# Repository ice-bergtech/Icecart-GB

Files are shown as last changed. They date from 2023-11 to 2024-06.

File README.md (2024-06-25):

# Icecart-GB

Another ROM Cartridge for the Gameboy.
Purpose is to fit the form factor of a gameboy cartridge and act as a ROM cartridge while also providing an arduino-like interface.
Emulates the functionality of an official cart, with the different bank controllers implemented in software.

[Schematic](GB-ICECART-GB-Alpha/schematic/GB-ICECART-GB.pdf)

PCB

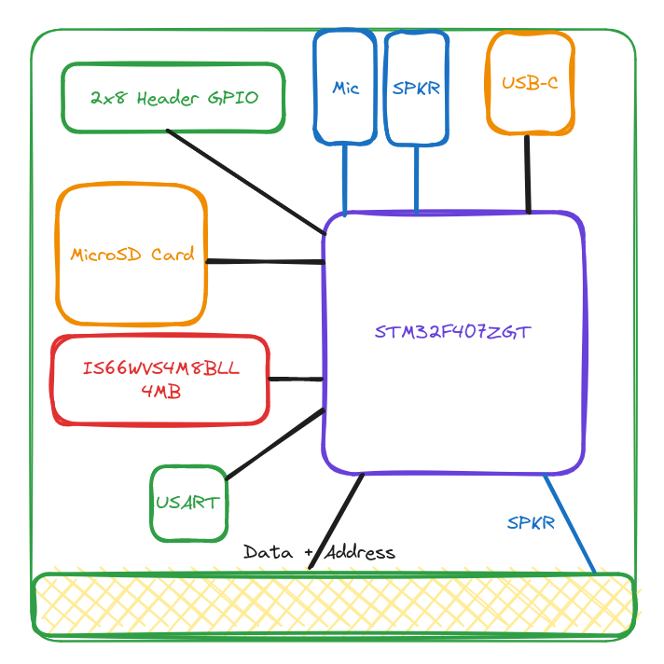
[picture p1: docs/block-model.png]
Block Model


It should also have functionality similar to an arduino, where you can interface with it through GPIO and audio in/out.
It should be as low-power as possible, since it will run off the gameboy battery.
It should support an sd card for storage while powered off.

Requirements:

* STM32-type processor
  * low power
  * Enough pins for cart and GPIO (32+16)
  * rtc
* External mic + speaker 3.8mm jacks
* dac connection to gameboy cartridge audio line for input
* usb C for programming / updating
* 2x8 or 2x6 GPIO
* microsd card slot for storage
* 32Mbit serial ram
* Respond to gameboy cartridge read/write (1MHz ??? Not sure) 
  * 4Mihz for gameboy: [gekkio notes](https://gekkio.fi/files/gb-docs/gbctr.pdf) appendix C
  * 8Mihz for gameboy color?
  * More timing information: https://dhole.github.io/post/gameboy_cartridge_emu_1/
* gameboy dmg/color cartridge footprint
  * https://github.com/Gekkio/gb-hardware/tree/main/GB-BRK-CART
* FreeRTOS

Examples:

* emeryth-hacks: https://emeryth.net/stm32-game-boy-cartridge/
* gekkio: https://github.com/Gekkio/gb-hardware#gb-live32

References:

[Old Memory bank controllers](https://mgba-emu.github.io/gbdoc/#mbc)
[TPP1 mapper](https://github.com/aaaaaa123456789/tpp1)

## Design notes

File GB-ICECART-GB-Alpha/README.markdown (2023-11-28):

# Notes

* The power LED (+ resistor) and the bypass capacitor are optional.
* The value of R1 might be too high to get enough current for the LED and can
  be replaced with a lower value if necessary. The value is set quite high to
  minimize power usage and still works fine with the components I use.
* All parts in the BOM can be replaced with pretty much any similar parts.

## Memory

8 Megabit SRAM

https://www.mouser.com/ProductDetail/ISSI/IS66WVS4M8BLL-104NLI?qs=doiCPypUmgHfByEUFkOsAw%3D%3D
https://www.issi.com/WW/pdf/66-67WVS4M8ALL-BLL.pdf

SPI

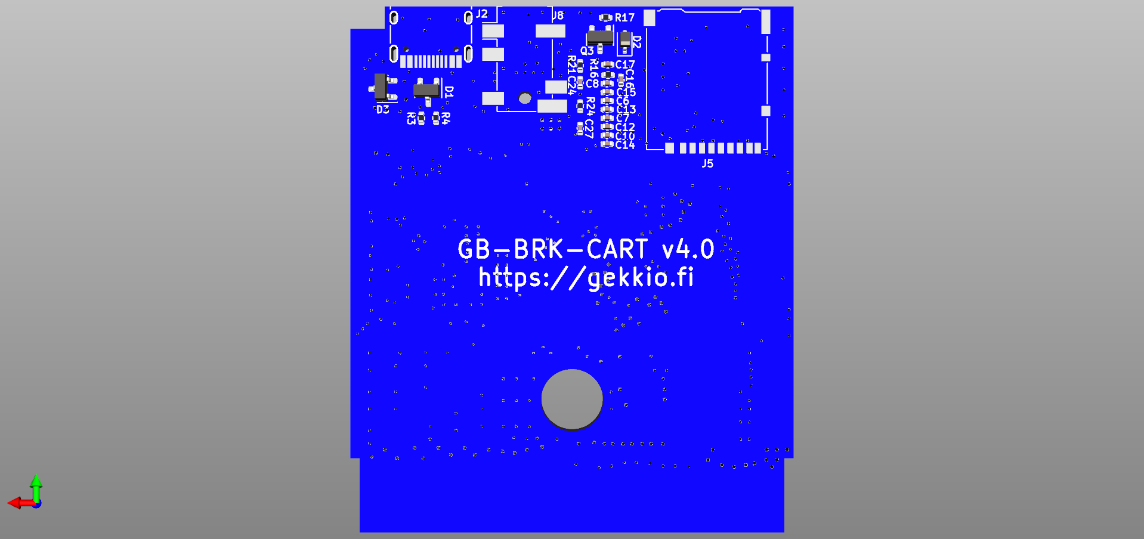
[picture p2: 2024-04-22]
ICECART-GB/images/GAMEBOY_STM32_CART 1.png

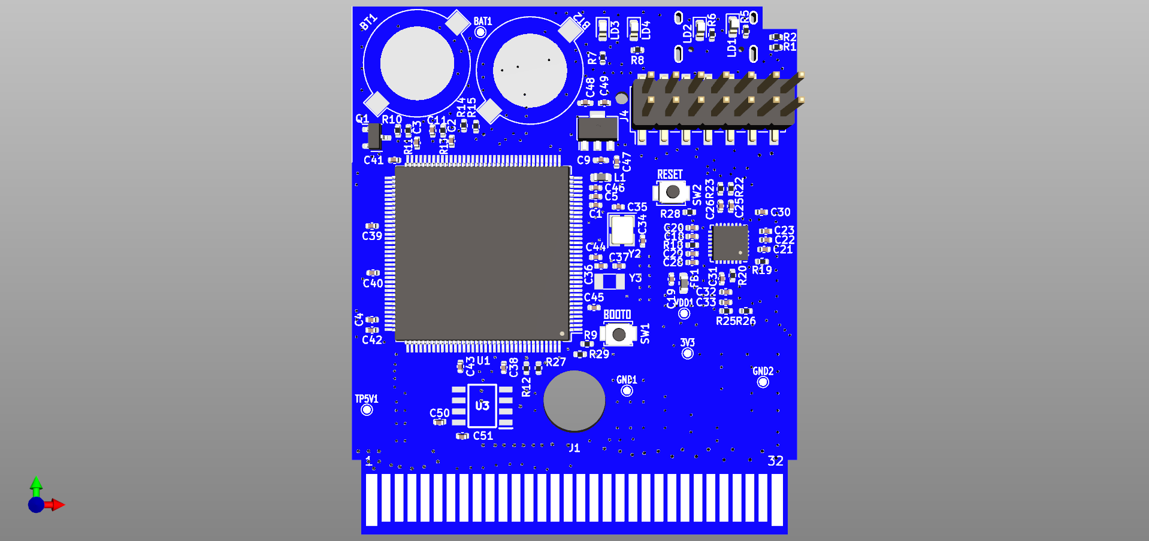
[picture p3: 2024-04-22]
ICECART-GB/images/GAMEBOY_STM32_CART.png

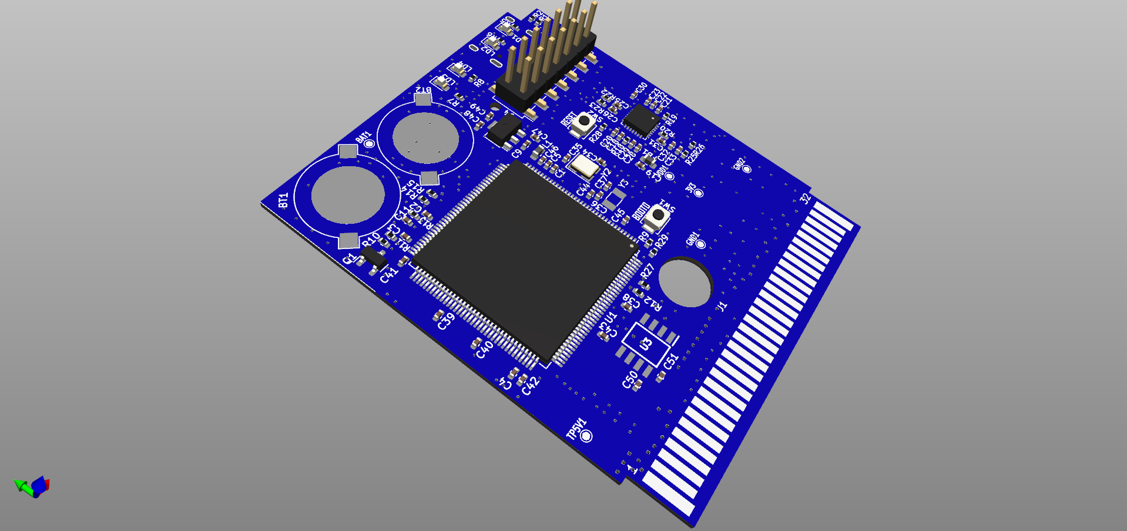
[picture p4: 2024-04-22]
ICECART-GB/images/GAMEBOY_STM32_CART 2.png

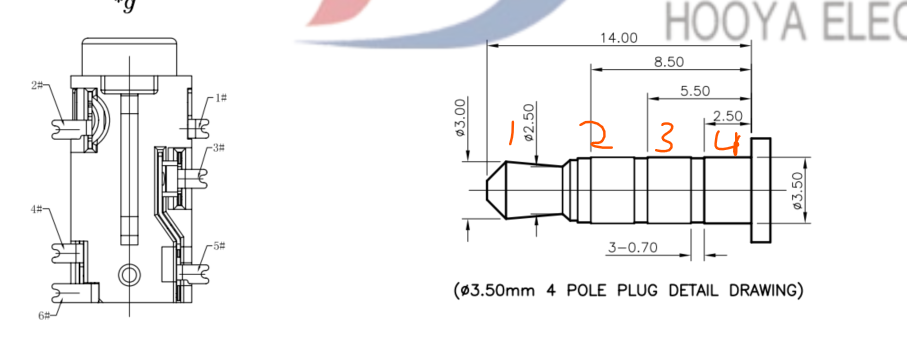
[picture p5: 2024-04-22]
ICECART-GB/ASSETS/mic_connection.png

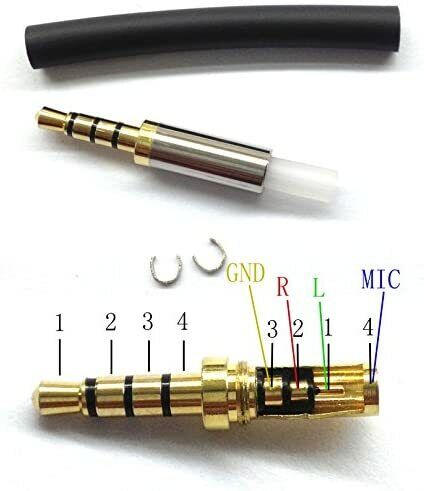
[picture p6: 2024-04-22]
ICECART-GB/ASSETS/jack_connection.png

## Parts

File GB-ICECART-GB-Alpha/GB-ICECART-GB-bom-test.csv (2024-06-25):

Reference | Value | Datasheet | Footprint | Qty | DNP
C1,C2 | 15p | -- mixed values -- | Capacitor_SMD:C_0603_1608Metric | 2
C3,C4 | 2.2uF |  | Capacitor_SMD:C_0603_1608Metric | 2
C5 | 10 | ~ | Capacitor_SMD:C_0603_1608Metric | 1
C6,C7,C8,C9,C10,C12,C13,C14,C15 | 100nF | -- mixed values -- | Capacitor_SMD:C_0603_1608Metric | 9
C11 | 0.1uF |  | Capacitor_SMD:C_0603_1608Metric | 1
C16 | 1uF | ~ | Capacitor_SMD:C_0603_1608Metric | 1
J1,MK1,MK2 | DNF |  | -- mixed values -- | 3
J2 | TYPE-C-31-M-12 | https://www.usb.org/sites/default/files/documents/usb_type-c.zip | Connector_USB:USB_C_Receptacle_HRO_TYPE-C-31-M-12 | 1
J3 | AudioJack3 | ~ | Connector_Audio:Jack_3.5mm_CUI_SJ1-3523N_Horizontal | 1
J4 | Conn_02x08_Odd_Even | ~ | Connector_IDC:IDC-Header_2x08_P2.54mm_Vertical_SMD | 1
J5 | Micro_SD_Card_Det | https://www.hirose.com/product/en/download_file/key_name/DM3/category/Catalog/doc_file_id/49662/?item_id=195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 | Connector_Card:microSD_HC_Hirose_DM3AT-SF-PEJM5 | 1
L1 | L | ~ | Inductor_SMD:L_6.3x6.3_H3 | 1
LD1 | Green | ~ | LED_SMD:LED_0603_1608Metric | 1
LD2 | Orange | ~ | LED_SMD:LED_0603_1608Metric | 1
LD3 | RED | ~ | LED_SMD:LED_0603_1608Metric | 1
LD4 | Blue | ~ | LED_SMD:LED_0603_1608Metric | 1
Q1 | AO3401A | http://www.aosmd.com/pdfs/datasheet/AO3401A.pdf | Package_TO_SOT_SMD:SOT-23 | 1
R1,R2 | 5k1 | ~ | Resistor_SMD:R_0603_1608Metric | 2
R3,R4 | 20 | ~ | Resistor_SMD:R_0603_1608Metric | 2
R5,R6,R7,R8 | 510 | ~ | Resistor_SMD:R_0603_1608Metric | 4
R9 | 10k | ~ | Resistor_SMD:R_0603_1608Metric | 1
R10,R11,R13,R14,R15 | 47K | ~ | Resistor_SMD:R_0603_1608Metric | 5
R16 | 0 | ~ | Resistor_SMD:R_0603_1608Metric | 1
SW1 | SW_Push | ~ | Button_Switch_SMD:SW_SPST_B3U-1000P | 1
U1 | STM32F407ZGTx | http://www.st.com/st-web-ui/static/active/en/resource/technical/document/datasheet/DM00037051.pdf | Package_QFP:LQFP-144_20x20mm_P0.5mm | 1
U2 | HT75xx-1-SOT89 | https://www.holtek.com/documents/10179/116711/HT75xx-1v250.pdf | Package_TO_SOT_SMD:SOT-89-3 | 1
U3 | IS66WVS4M8BLL-104NLI |  | IS66WVS4M8BLL:SOIC127P600X175-8N | 1
Y1 | Crystal 8M | ~ | Crystal:Crystal_SMD_TXC_7M-4Pin_3.2x2.5mm | 1

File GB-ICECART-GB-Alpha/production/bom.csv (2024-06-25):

Designator | Footprint | Quantity | Value | LCSC Part #
C1, C2 | 0603 | 2 | 15p | 06035C104KAT4A
C10, C12, C13, C14, C15, C6, C7, C8 | 0603 | 8 | 100nF
C11 | 0603 | 1 | 0.1uF | 06035C104KAT4A
C16 | 0603 | 1 | 1uF
C3, C4 | 0603 | 2 | 2.2uF | 06035C104KAT4A
C5 | 0603 | 1 | 10
C9 | 0603 | 1 | 100nF | 06035C104KAT4A
J1 | GameBoy_Cartridge_1x32_P1.50mm_Edge | 1 | DNF
J2 | USB_C_Receptacle_HRO_TYPE-C-31-M-12 | 1 | TYPE-C-31-M-12
J3 | Jack_3.5mm_CUI_SJ1-3523N_Horizontal | 1 | AudioJack3
J4 | IDC-Header_2x08_P2.54mm_Vertical_SMD | 1 | Conn_02x08_Odd_Even
J5 | microSD_HC_Hirose_DM3AT-SF-PEJM5 | 1 | Micro_SD_Card_Det
L1 | L_6.3x6.3_H3 | 1 | L
LD1 | 0603 | 1 | Green
LD2 | 0603 | 1 | Orange
LD3 | 0603 | 1 | RED
LD4 | 0603 | 1 | Blue
MK1 | MountingHole_7.2mm | 1 | DNF
Q1 | SOT-23 | 1 | AO3401A
R1, R2 | 0603 | 2 | 5k1
R10, R11, R13, R14, R15 | 0603 | 5 | 47K
R16 | 0603 | 1 | 0
R3, R4 | 0603 | 2 | 20
R5, R6, R7, R8 | 0603 | 4 | 510
R9 | 0603 | 1 | 10k
SW1 | SW_SPST_B3U-1000P | 1 | SW_Push
U1 | LQFP-144_20x20mm_P0.5mm | 1 | STM32F407ZGTx
U2 | SOT-89-3 | 1 | HT75xx-1-SOT89
U3 | SOIC127P600X175-8N | 1 | IS66WVS4M8BLL-104NLI
Y1 | Crystal_SMD_TXC_7M-4Pin_3.2x2.5mm | 1 | Crystal 8M

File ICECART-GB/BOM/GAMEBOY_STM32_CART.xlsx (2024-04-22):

Reference(s) | Value | Footprint | MPN | Vendor | Qty
BT1, BT2 | Battery_Cell | greencharge-footprints:AG10-LR1130-BUTTONCELL_BAT | https://www.alibaba.com/product-detail/Metal-alkaline-1-5V-AG10-LR1130_60831977476.html | Alibaba | 2
C1, C19, C23, C33, C51 | 10u | Capacitor_SMD:C_0402_1005Metric | CL05A106MQ5NUNC | LCSC | 5
C2, C6, C7, C8, C10, C11, C12, C13, C14, C15, C18, C20, C21, C22, C28, C29, C30, C32, C38, C39, C40, C41, C42, C43, C44, C45, C46, C50 | 100n | Capacitor_SMD:C_0402_1005Metric | CL05B104KB54PNC | LCSC | 28
C3, C4 | 2.2uF | Capacitor_SMD:C_0402_1005Metric | 06035C104KAT4A | LCSC | 2
C5, C47, C49 | 10u | Capacitor_SMD:C_0402_1005Metric | CL05A106MQ5NUNC | LCSC | 3
C9, C48 | 100nF | Capacitor_SMD:C_0402_1005Metric_Pad0.74x0.62mm_HandSolder | CL05B104KB54PNC | LCSC | 2
C16, C31 | 1uF | Capacitor_SMD:C_0402_1005Metric | CL05A105KO5NNNC | LCSC | 2
C17 | 4.7u | Capacitor_SMD:C_0402_1005Metric | CL05A475MQ5NRNC | LCSC | 1
C24, C25, C26, C27 | 22u | Capacitor_SMD:C_0402_1005Metric | GRM155R60J226ME11D | LCSC | 4
C34, C35, C36, C37 | 22p | Capacitor_SMD:C_0402_1005Metric | 06035C104KAT4A | LCSC | 4
D1, D3 | SP0502BAHT | Package_TO_SOT_SMD:SOT-23 | SP0502BAHTG | LCSC | 2
D2 | D_Schottky_Small | Diode_SMD:D_SOD-323 | B5817WS | LCSC | 1
FB1, L1 | L | Inductor_SMD:L_0603_1608Metric | BLM18SG121TN1D | LCSC | 2
J2 | TYPE-C-31-M-12 | Connector_USB:USB_C_Receptacle_HRO_TYPE-C-31-M-12 | TYPE-C-31-M-12 | LCSC | 1
J4 | Conn_02x08_Odd_Even | Connector_PinHeader_2.54mm:PinHeader_2x07_P2.54mm_Vertical_SMD | PZ254-2-07-S | LCSC | 1
J5 | Micro_SD_Card_Det | Connector_Card:microSD_HC_Hirose_DM3AT-SF-PEJM5 | DM3AT-SF-PEJM5 | LCSC | 1
J8 | AudioJack3_Ground | Connector_Audio:Jack_3.5mm_PJ31060-I_Horizontal | PJ-31060 | LCSC | 1
LD1 | Green | LED_SMD:LED_0603_1608Metric | LTST-C193KGKT-5A | LCSC | 1
LD2 | Orange | LED_SMD:LED_0603_1608Metric | LTST-C193KFKT-5A | LCSC | 1
LD3 | RED | LED_SMD:LED_0603_1608Metric | LTST-C193KRKT-5A | LCSC | 1
LD4 | Blue | LED_SMD:LED_0603_1608Metric | LTST-C193TBKT-5A | LCSC | 1
Q1 | AO3401A | Package_TO_SOT_SMD:SOT-23 | AO3401A | LCSC | 1
Q3 | PJM2319PSA | Package_TO_SOT_SMD:SOT-23 | PJM2319PSA | LCSC | 1
R1, R2 | 5k1 | Resistor_SMD:R_0402_1005Metric | 0402WGF5101TCE | LCSC | 2
R3, R4 | 20R | Resistor_SMD:R_0402_1005Metric | 0402WGF200JTCE | LCSC | 2
R5, R6, R7, R8 | 510R | Resistor_SMD:R_0402_1005Metric | 0402WGF5100TCE | LCSC | 4
R9, R17, R20, R28 | 10k | Resistor_SMD:R_0402_1005Metric | RC0402FR-0710KL | LCSC | 4
R10, R11, R13, R14, R15 | 47K | Resistor_SMD:R_0402_1005Metric | 0402WGF4702TCE | LCSC | 5
R12, R27 | 4.7K | Resistor_SMD:R_0402_1005Metric | 0402WGF4701TCE | LCSC | 2
R18 | 4.7R | Resistor_SMD:R_0402_1005Metric | 0402WGF470KTCE | LCSC | 1
R19 | 100R | Resistor_SMD:R_0402_1005Metric | 0402WGF1000TCE | LCSC | 1
R16, R21, R24, R29 | 0R | Resistor_SMD:R_0402_1005Metric | 0402WGF0000TCE | LCSC | 4
R22, R23 | 33R | Resistor_SMD:R_0402_1005Metric | 0402WGF330JTCE | LCSC | 2
R25 | 2K | Resistor_SMD:R_0402_1005Metric | 0402WGF2001TCE | LCSC | 1
R26 | 1K | Resistor_SMD:R_0402_1005Metric | 0402WGF1001TCE | LCSC | 1
SW1, SW2 | SW_Push | Button_Switch_SMD:SW_SPST_B3U-1000P | B3U-1000P | LCSC | 2
U1 | STM32F407ZGTx | Package_QFP:LQFP-144_20x20mm_P0.5mm | STM32F407ZGT6 | LCSC | 1
U2 | HT75xx-1-SOT89 | Package_TO_SOT_SMD:SOT-89-3 | HT7550 | LCSC | 1
U3 | IS66WVS4M8BLL-104NLI | IS66WVS4M8BLL:SOIC127P600X175-8N | https://www.alibaba.com/product-detail/-Electronic-components-IS66WVS4M8BLL-104NLI_1601080803118.html | Alibaba | 1
U4 | ES8388 | Package_DFN_QFN:QFN-28-1EP_4x4mm_P0.45mm_EP2.4x2.4mm | ES8388 | LCSC | 1
Y2 | 8MHz | Crystal:Crystal_SMD_3225-4Pin_3.2x2.5mm | TAXM8M4RDBCCT2T | LCSC | 1
Y3 | 32.768KHz | Crystal:Crystal_SMD_3215-2Pin_3.2x1.5mm | Q13FC13500004 | LCSC | 1

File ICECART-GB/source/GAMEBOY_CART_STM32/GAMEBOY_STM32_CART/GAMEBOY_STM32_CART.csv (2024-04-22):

Source: | C:\Users\user\Documents\kicad6\KICAD 6.0.0\wozniak\GAMEBOY_CART_ROM_STM32\source\GAMEBOY_CART_STM32\GAMEBOY_STM32_CART\GAMEBOY_STM32_CART.kicad_sch
Date: | 4/17/2024 9:49:46 PM
Tool: | Eeschema 7.0.10
Generator: | C:\Program Files\KiCad\7.0\bin\scripting\plugins/bom_csv_grouped_by_value.py
Component Count: | 114
Collated Components:
Item | Qty | Reference(s) | Value | LibPart | Footprint | Datasheet | DNP | Datasheet_1 | Description | Footprint_1 | Height | MFR | MPN | Manufacturer_Name | Manufacturer_Part_Number | Mouser Part Number | Mouser Price/Stock | Package | Rating | Reference_1 | SPN | SPR | Value_1 | Voltage
1 | 1 | 3V3 | 3V3 | Connector:TestPoint | brilliant-kicad-library:TestPoint_Pad_D0.9mm | ~
2 | 1 | BAT1 | BAT | Connector:TestPoint | brilliant-kicad-library:TestPoint_Pad_D0.9mm | ~
3 | 2 | BT1, BT2 | Battery_Cell | Device:Battery_Cell | greencharge-footprints:AG10-LR1130-BUTTONCELL_BAT | ~
4 | 5 | C1, C19, C23, C33, C51 | 10u | Device:C_Small | Capacitor_SMD:C_0402_1005Metric | ~
5 | 19 | C2, C18, C20, C21, C22, C28, C29, C30, C32, C38, C39, C40, C41, C42, C43, C44, C45, C46, C50 | 100n | Device:C_Small | Capacitor_SMD:C_0402_1005Metric | ~
6 | 2 | C3, C4 | 2.2uF | Device:C | Capacitor_SMD:C_0402_1005Metric | ~ |  |  |  |  |  | AVX | 06035C104KAT4A |  |  |  |  |  | 16V X5R |  | 581-06035C104KAT4A | Mouser
7 | 3 | C5, C47, C49 | 10u | :C_1 | Capacitor_SMD:C_0402_1005Metric | ~
8 | 8 | C6, C7, C8, C10, C12, C13, C14, C15 | 100nF | :C_1 | Capacitor_SMD:C_0402_1005Metric | ~
9 | 2 | C9, C48 | 100nF | Device:C | Capacitor_SMD:C_0402_1005Metric_Pad0.74x0.62mm_HandSolder | ~ |  |  |  |  |  | AVX | 06035C104KAT4A |  |  |  |  |  | 16V X5R |  | 581-06035C104KAT4A | Mouser
10 | 1 | C11 | 0.1uF | Device:C | Capacitor_SMD:C_0402_1005Metric | ~ |  |  |  |  |  | AVX | 06035C104KAT4A |  |  |  |  |  | 16V X5R |  | 581-06035C104KAT4A | Mouser
11 | 1 | C16 | 1uF | :C_1 | Capacitor_SMD:C_0402_1005Metric | ~
12 | 1 | C17 | 4.7u | Device:C_Small | Capacitor_SMD:C_0402_1005Metric | ~ |  |  | X5R |  |  |  |  |  |  |  |  | 0603 |  |  |  |  |  | 10V
13 | 4 | C24, C25, C26, C27 | 22u | Device:C_Small | Capacitor_SMD:C_0402_1005Metric | ~
14 | 1 | C31 | 1u | Device:C_Small | Capacitor_SMD:C_0402_1005Metric | ~
15 | 1 | C34 | 22p | :C_2 | Capacitor_SMD:C_0402_1005Metric | ~ |  |  |  |  |  | AVX | 06035C104KAT4A |  |  |  |  |  | 16V X5R |  | 581-06035C104KAT4A | Mouser
16 | 3 | C35, C36, C37 | 22p | Device:C | Capacitor_SMD:C_0402_1005Metric | ~ |  |  |  |  |  | AVX | 06035C104KAT4A |  |  |  |  |  | 16V X5R |  | 581-06035C104KAT4A | Mouser
17 | 2 | D1, D3 | SP0502BAHT | Power_Protection:SP0502BAHT | Package_TO_SOT_SMD:SOT-23 | http://www.littelfuse.com/~/media/files/littelfuse/technical%20resources/documents/data%20sheets/sp05xxba.pdf
18 | 1 | D2 | D_Schottky_Small | Device:D_Schottky_Small | Diode_SMD:D_SOD-323 | ~
19 | 2 | FB1, L1 | L | Device:L | Inductor_SMD:L_0603_1608Metric | ~ |  |  |  |  |  |  | BLM18SG121TN1D
20 | 2 | GND1, GND2 | GND | Connector:TestPoint | brilliant-kicad-library:TestPoint_Pad_D0.9mm | ~
21 | 1 | J1 | DNF | Gekkio_Connector_Specialized:GameBoy_Cartridge | Gekkio_Connector_PCBEdge:GameBoy_Cartridge_1x32_P1.50mm_Edge
22 | 1 | J2 | TYPE-C-31-M-12 | Connector:USB_C_Receptacle_USB2.0 | Connector_USB:USB_C_Receptacle_HRO_TYPE-C-31-M-12 | https://www.usb.org/sites/default/files/documents/usb_type-c.zip
23 | 1 | J4 | Conn_02x08_Odd_Even | Connector_Generic:Conn_02x08_Odd_Even | Connector_PinHeader_2.54mm:PinHeader_2x07_P2.54mm_Vertical_SMD | ~
24 | 1 | J5 | Micro_SD_Card_Det | Connector:Micro_SD_Card_Det | Connector_Card:microSD_HC_Hirose_DM3AT-SF-PEJM5 | https://www.hirose.com/product/en/download_file/key_name/DM3/category/Catalog/doc_file_id/49662/?item_id=195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
25 | 1 | J8 | AudioJack3_Ground | Connector_Audio:AudioJack3_Ground | Connector_Audio:Jack_3.5mm_PJ31060-I_Horizontal | ~
26 | 1 | LD1 | Green | :LED_1 | LED_SMD:LED_0603_1608Metric | ~
27 | 1 | LD2 | Orange | :LED_1 | LED_SMD:LED_0603_1608Metric | ~
28 | 1 | LD3 | RED | :LED_1 | LED_SMD:LED_0603_1608Metric | ~
29 | 1 | LD4 | Blue | :LED_1 | LED_SMD:LED_0603_1608Metric | ~
30 | 1 | MK1 | DNF | Mechanical:Mounting_Hole | Gekkio_MountingHole:MountingHole_7.2mm
31 | 1 | MK2 | DNF | Mechanical:Mounting_Hole | Gekkio_MountingHole:MountingHole_2.3mm
32 | 1 | Q1 | AO3401A | Transistor_FET:AO3401A | Package_TO_SOT_SMD:SOT-23 | http://www.aosmd.com/pdfs/datasheet/AO3401A.pdf
33 | 1 | Q3 | PJM2319PSA | Device:Q_PMOS_GSD | Package_TO_SOT_SMD:SOT-23 | ~
34 | 2 | R1, R2 | 5k1 | Device:R | Resistor_SMD:R_0402_1005Metric | ~
35 | 2 | R3, R4 | 20 | :R_US_1 | Resistor_SMD:R_0402_1005Metric | ~
36 | 1 | R5 | 510 | :R_US_1 | Resistor_SMD:R_0402_1005Metric | ~
37 | 3 | R6, R7, R8 | 510 | Device:R_US | Resistor_SMD:R_0402_1005Metric | ~
38 | 2 | R9, R28 | 10k | :R_US_1 | Resistor_SMD:R_0402_1005Metric | ~
39 | 5 | R10, R11, R13, R14, R15 | 47K | :R_US_1 | Resistor_SMD:R_0402_1005Metric | ~
40 | 2 | R12, R27 | 4.7K | :R_US_1 | Resistor_SMD:R_0402_1005Metric | ~
41 | 1 | R16 | 0 | :R_US_1 | Resistor_SMD:R_0402_1005Metric | ~
42 | 1 | R17 | 10k | Device:R_Small_US | Resistor_SMD:R_0402_1005Metric | ~
43 | 1 | R18 | 4.7R | Device:R_US | Resistor_SMD:R_0402_1005Metric | ~
44 | 1 | R19 | 100R | Device:R_US | Resistor_SMD:R_0402_1005Metric | ~
45 | 1 | R20 | 10K | Device:R_US | Resistor_SMD:R_0402_1005Metric | ~
46 | 2 | R21, R24 | 0R | Device:R_US | Resistor_SMD:R_0402_1005Metric | ~
47 | 2 | R22, R23 | 33R | Device:R_US | Resistor_SMD:R_0402_1005Metric | ~
48 | 1 | R25 | 2K | Device:R_US | Resistor_SMD:R_0402_1005Metric | ~
49 | 1 | R26 | 1K | Device:R_US | Resistor_SMD:R_0402_1005Metric | ~
50 | 1 | R29 | 0R | :R_US_1 | Resistor_SMD:R_0402_1005Metric | ~
51 | 2 | SW1, SW2 | SW_Push | Switch:SW_Push | Button_Switch_SMD:SW_SPST_B3U-1000P | ~
52 | 1 | TP5V1 | 5V | Connector:TestPoint | brilliant-kicad-library:TestPoint_Pad_D0.9mm | ~
53 | 1 | U1 | STM32F407ZGTx | MCU_ST_STM32F4:STM32F407ZGTx | Package_QFP:LQFP-144_20x20mm_P0.5mm | http://www.st.com/st-web-ui/static/active/en/resource/technical/document/datasheet/DM00037051.pdf
54 | 1 | U2 | HT75xx-1-SOT89 | Regulator_Linear:HT75xx-1-SOT89 | Package_TO_SOT_SMD:SOT-89-3 | https://www.holtek.com/documents/10179/116711/HT75xx-1v250.pdf |  |  |  |  |  |  | HT7550
55 | 1 | U3 | IS66WVS4M8BLL-104NLI | IS66WVS4M8BLL:IS66WVS4M8BLL-104NLI | IS66WVS4M8BLL:SOIC127P600X175-8N |  |  | https://www.issi.com/WW/pdf/66-67WVS4M8ALL-BLL.pdf |  | SOIC127P600X175-8N | 1.75 |  |  | Integrated Silicon Solution Inc. | IS66WVS4M8BLL-104NLI | 870-ISS4M8BLL-104NLI | https://www.mouser.co.uk/ProductDetail/ISSI/IS66WVS4M8BLL-104NLI?qs=doiCPypUmgHfByEUFkOsAw%3D%3D |  |  | IC |  |  | IS66WVS4M8BLL-104NLI
56 | 1 | U4 | ES8388 | MCD_Integrated_IC:ES8388 | Package_DFN_QFN:QFN-28-1EP_4x4mm_P0.45mm_EP2.4x2.4mm
57 | 1 | VDD1 | VDD | Connector:TestPoint | brilliant-kicad-library:TestPoint_Pad_D0.9mm | ~
58 | 1 | Y2 | 8MHz | Device:Crystal_GND24_Small | Crystal:Crystal_SMD_3225-4Pin_3.2x2.5mm | ~ |  |  |  |  |  |  | TAXM8M4RDBCCT2T
59 | 1 | Y3 | 32.768KHz | Device:Crystal | Crystal:Crystal_SMD_3215-2Pin_3.2x1.5mm | ~ |  |  |  |  |  |  | Q13FC13500004

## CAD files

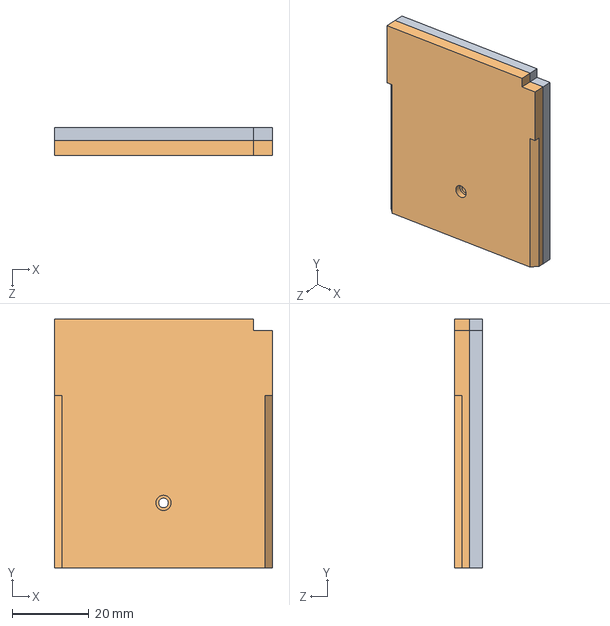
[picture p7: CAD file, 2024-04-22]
ICECART-GB/ASSETS/gbcase.SLDASM
57.0 x 65.0 x 7.40 mm
gbcase-bottom.step
gbcase-top.step

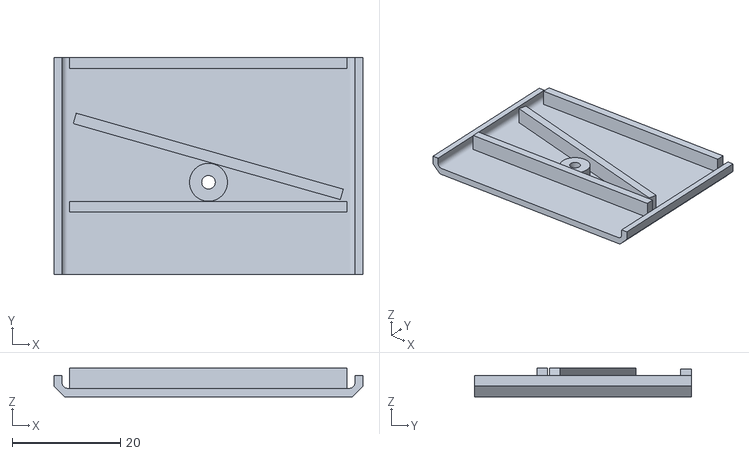
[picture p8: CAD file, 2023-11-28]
GB-ICECART-GB-Alpha/case/gbcase-top-debug-supports.stl
57.0 x 40.0 x 5.34

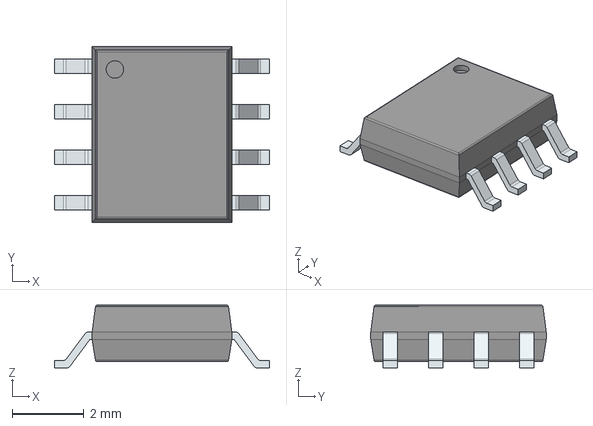
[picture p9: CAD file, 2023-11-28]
GB-ICECART-GB-Alpha/symbols/LIB_IS66WVS4M8BLL-104NLI/IS66WVS4M8BLL-104NLI/3D/IS66WVS4M8BLL-104NLI.stp
6.00 x 4.90 x 1.75 mm
PinsArrayLR

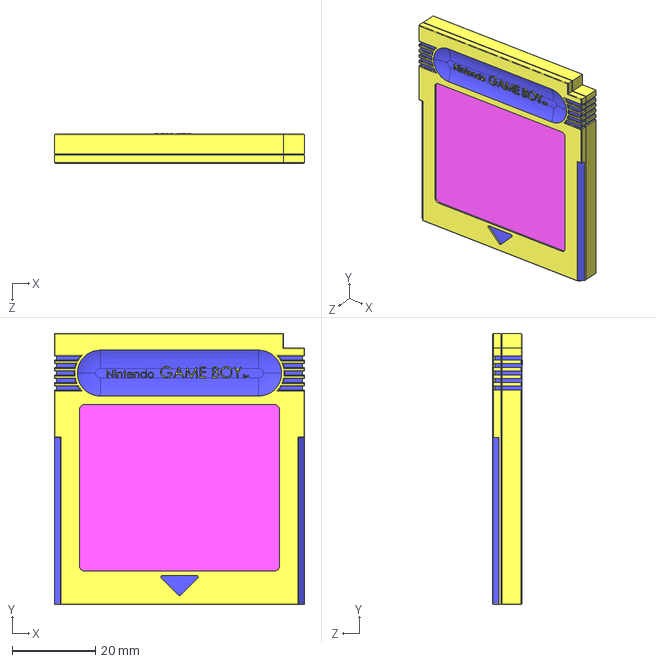
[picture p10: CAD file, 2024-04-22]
ICECART-GB/ASSETS/CARTRIDGE.STEP
60.0 x 65.0 x 7.10 mm

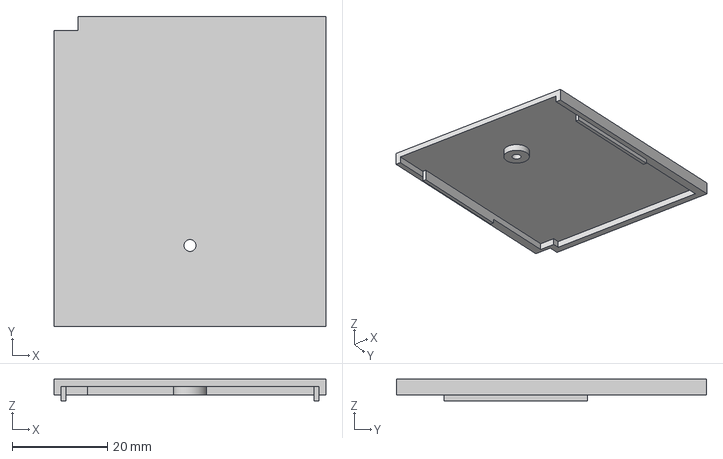
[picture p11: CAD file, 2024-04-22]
ICECART-GB/ASSETS/step_files/gbcase-main/gbcase-main/gbcase-bottom-debug.step
57.0 x 65.0 x 4.60 mm

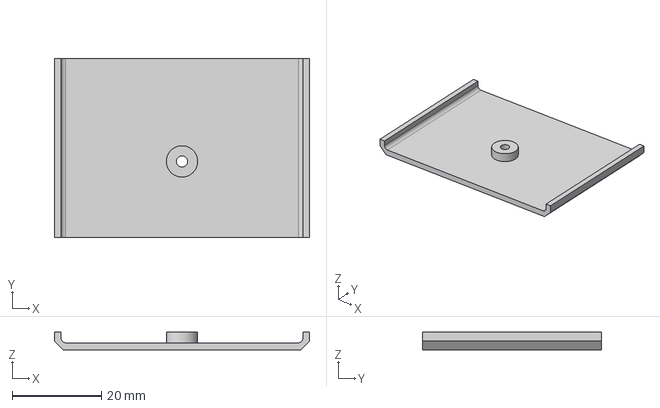
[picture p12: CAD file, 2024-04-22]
ICECART-GB/ASSETS/step_files/gbcase-main/gbcase-main/gbcase-top-debug.step
57.0 x 40.0 x 4.00 mm

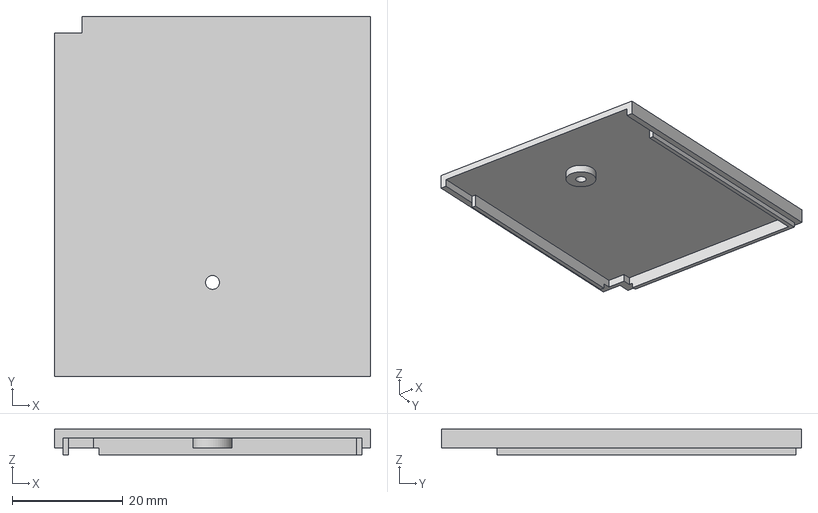
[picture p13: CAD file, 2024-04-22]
ICECART-GB/ASSETS/step_files/gbcase-main/gbcase-main/gbcase-bottom.step
57.0 x 65.0 x 4.60 mm

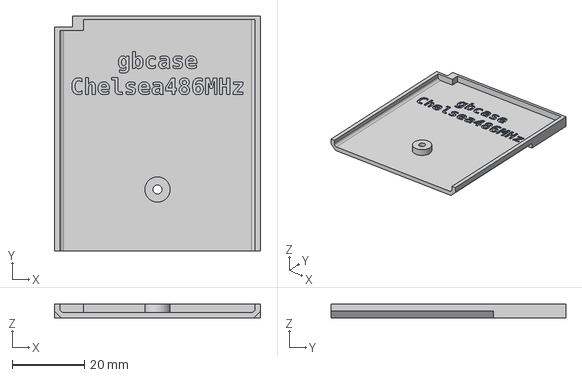
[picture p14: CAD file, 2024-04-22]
ICECART-GB/ASSETS/step_files/gbcase-main/gbcase-main/gbcase-top.step
57.0 x 65.0 x 4.00 mm

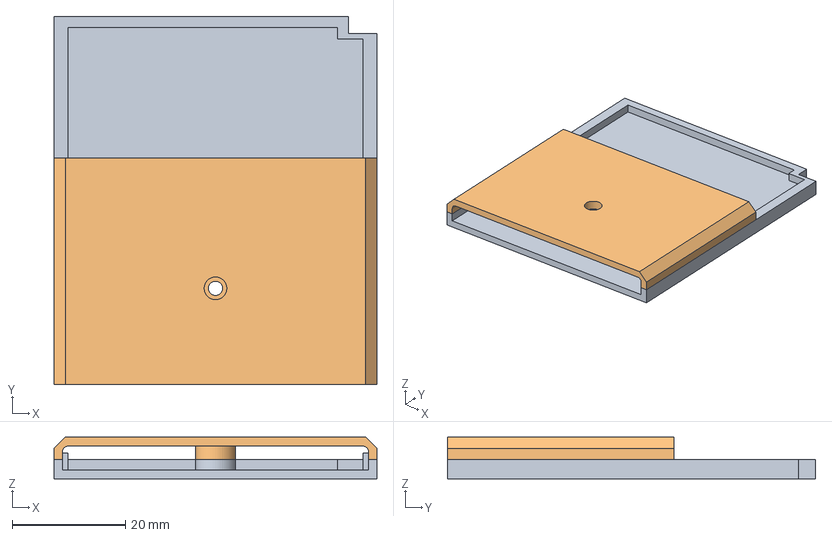
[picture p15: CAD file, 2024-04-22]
ICECART-GB/ASSETS/step_files/gbcase-main/gbcase-main/gbcase-debug.step
57.0 x 65.0 x 7.40 mm
gbcase-bottom-debug
gbcase-top-debug

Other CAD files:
GB-ICECART-GB-Alpha/case/gbcase-bottom-debug.stl
ICECART-GB/source/GAMEBOY_CART_STM32/GAMEBOY_STM32_CART/case/gbcase-bottom-debug.stl
ICECART-GB/ASSETS/step_files/gbcase-main/gbcase-main/gbcase.step
GB-ICECART-GB-Alpha/case/gb-case-bottom.blend
GB-ICECART-GB-Alpha/symbols/LIB_IS66WVS4M8BLL-104NLI/IS66WVS4M8BLL-104NLI/DEHDL/is66wvs4m8bll_104nli/chips/chips.prt
ICECART-GB/ASSETS/step_files/gbcase-main/gbcase-main/gbcase-bottom-debug.stl
ICECART-GB/ASSETS/step_files/gbcase-main/gbcase-main/gbcase-bottom.stl
ICECART-GB/ASSETS/step_files/gbcase-main/gbcase-main/gbcase-top-debug.stl
ICECART-GB/ASSETS/step_files/gbcase-main/gbcase-main/gbcase-top.stl
ICECART-GB/source/GAMEBOY_CART_STM32/GAMEBOY_STM32_CART/case/gb-case-bottom.blend
ICECART-GB/source/GAMEBOY_CART_STM32/GAMEBOY_STM32_CART/symbols/LIB_IS66WVS4M8BLL-104NLI/IS66WVS4M8BLL-104NLI/DEHDL/is66wvs4m8bll_104nli/chips/chips.prt

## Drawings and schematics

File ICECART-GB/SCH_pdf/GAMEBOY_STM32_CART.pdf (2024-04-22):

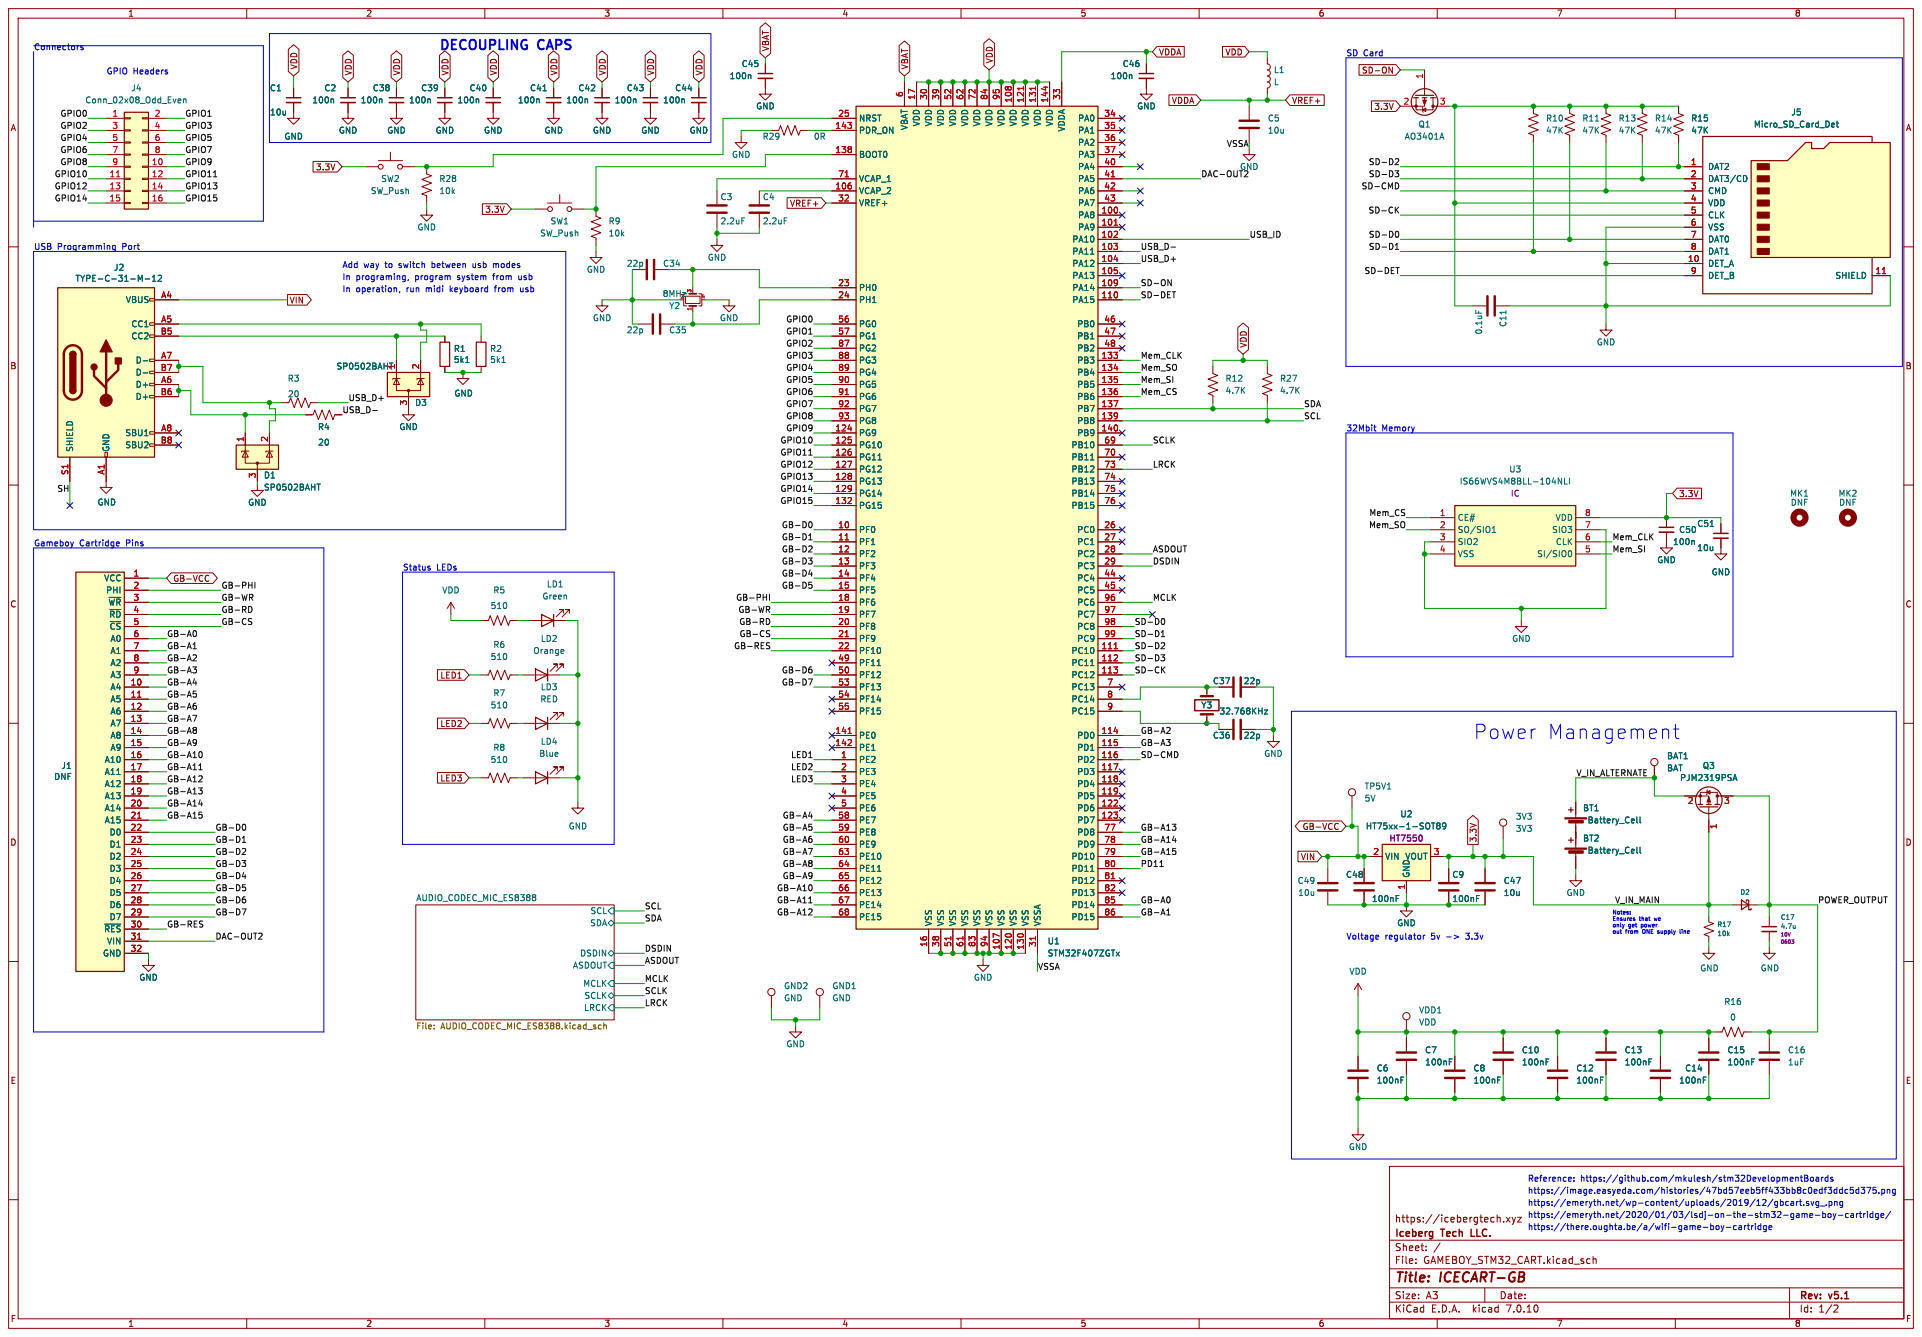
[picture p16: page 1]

100n GND GND GND GND

2 D1SP0502BAHT PE2 1 PF0 10 PA8 100 PA9 101 PA10 102 PA11 103 PA12 104 PA13 105 VCAP_2 106 VSS 107 VDD 108 PA14 109 PF1 11 PA15 110 PC10 111 PC11 112 PC12 113 PD0 114 PD1 115 PD2 116 PD3 117 PD4 118 PD5 119 PF2 12 VSS 120 VDD 121 PD6 122 PD7 123 PG9 124 PG10 125 PG11 126 PG12 127 PG13 128 PG14 129 PF3 13 VSS 130 VDD 131 PG15 132 PB3 133 PB4 134 PB5 135 PB6 136 PB7 137 BOOT0 138 PB8 139 PF4 14 PB9 140 PE0 141 PE1 142

32Mbit Memory Add way to switch between usb modes

SD-DET SD-CK

GPIO5 GPIO4 GPIO6 GB-PHI GB-A13 GB-A12

LRCK DSDIN
ASDOUT SD-CMD GB-A3

Notes: Ensures that we

https://image.easyeda.com/histories/47bd57eeb5ff433bb8c0edf3ddc5d375.png
https://emeryth.net/wp-content/uploads/2019/12/gbcart.svg_.png
https://emeryth.net/2020/01/03/lsdj-on-the-stm32-game-boy-cartridge/
https://there.oughta.be/a/wifi-game-boy-cartridge

File: GAMEBOY_STM32_CART.kicad_sch Sheet: /
Id: 1/2 Title: ICECART-GB

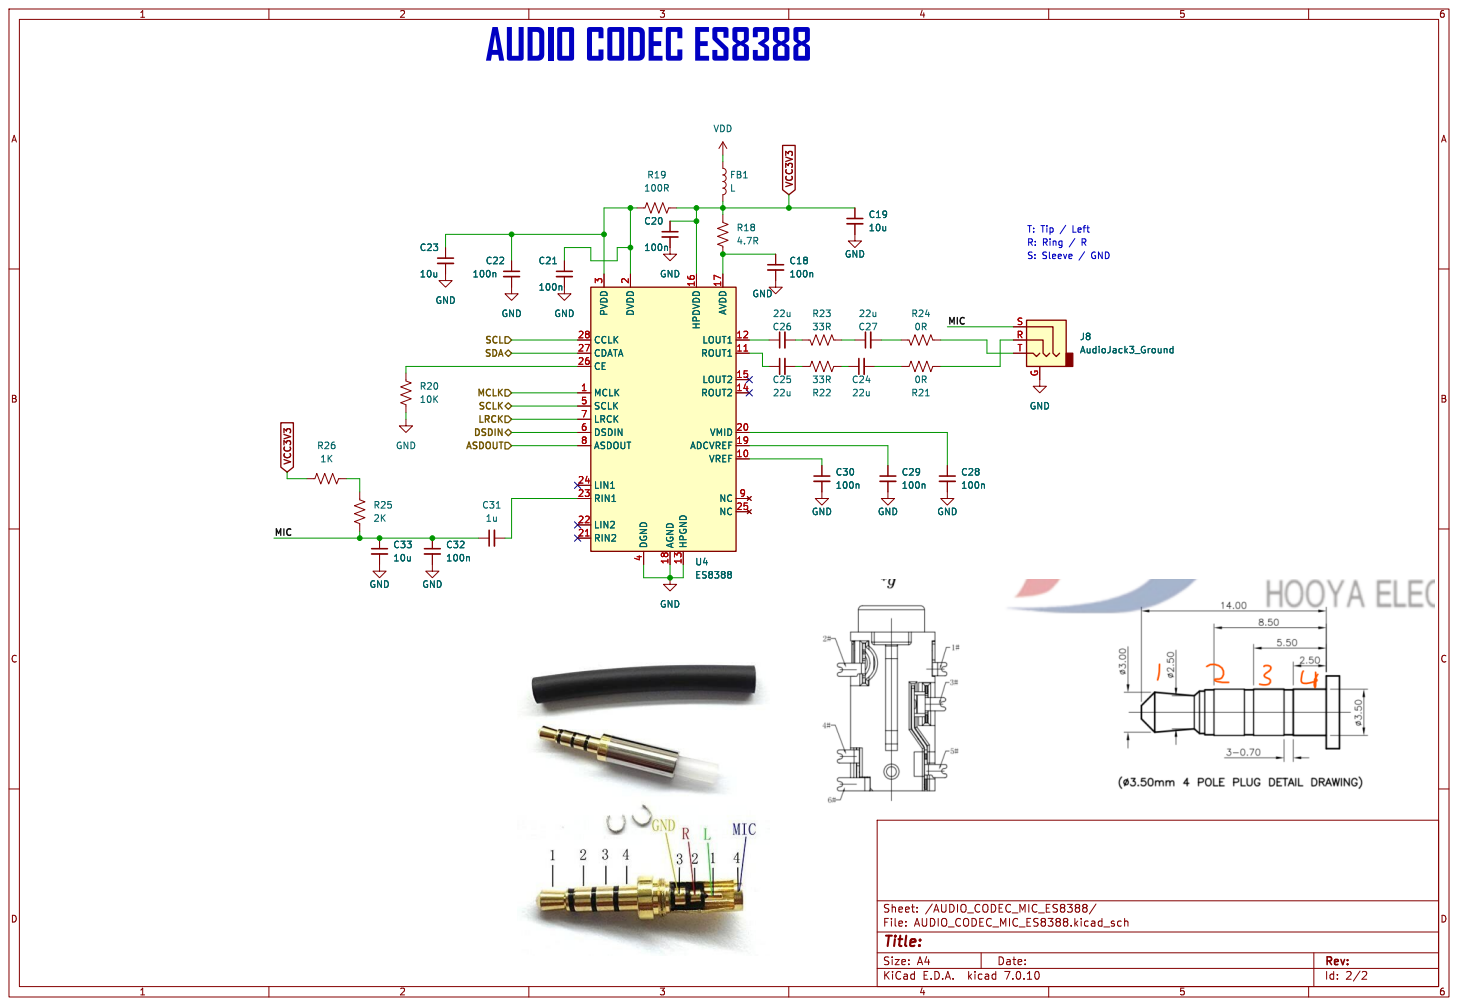
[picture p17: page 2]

T: Tip / Left S: Sleeve / GND AUDIOCODECES8388

Id: 2/2 Title: File: AUDIO_CODEC_MIC_ES8388.kicad_sch Sheet: /AUDIO_CODEC_MIC_ES8388/

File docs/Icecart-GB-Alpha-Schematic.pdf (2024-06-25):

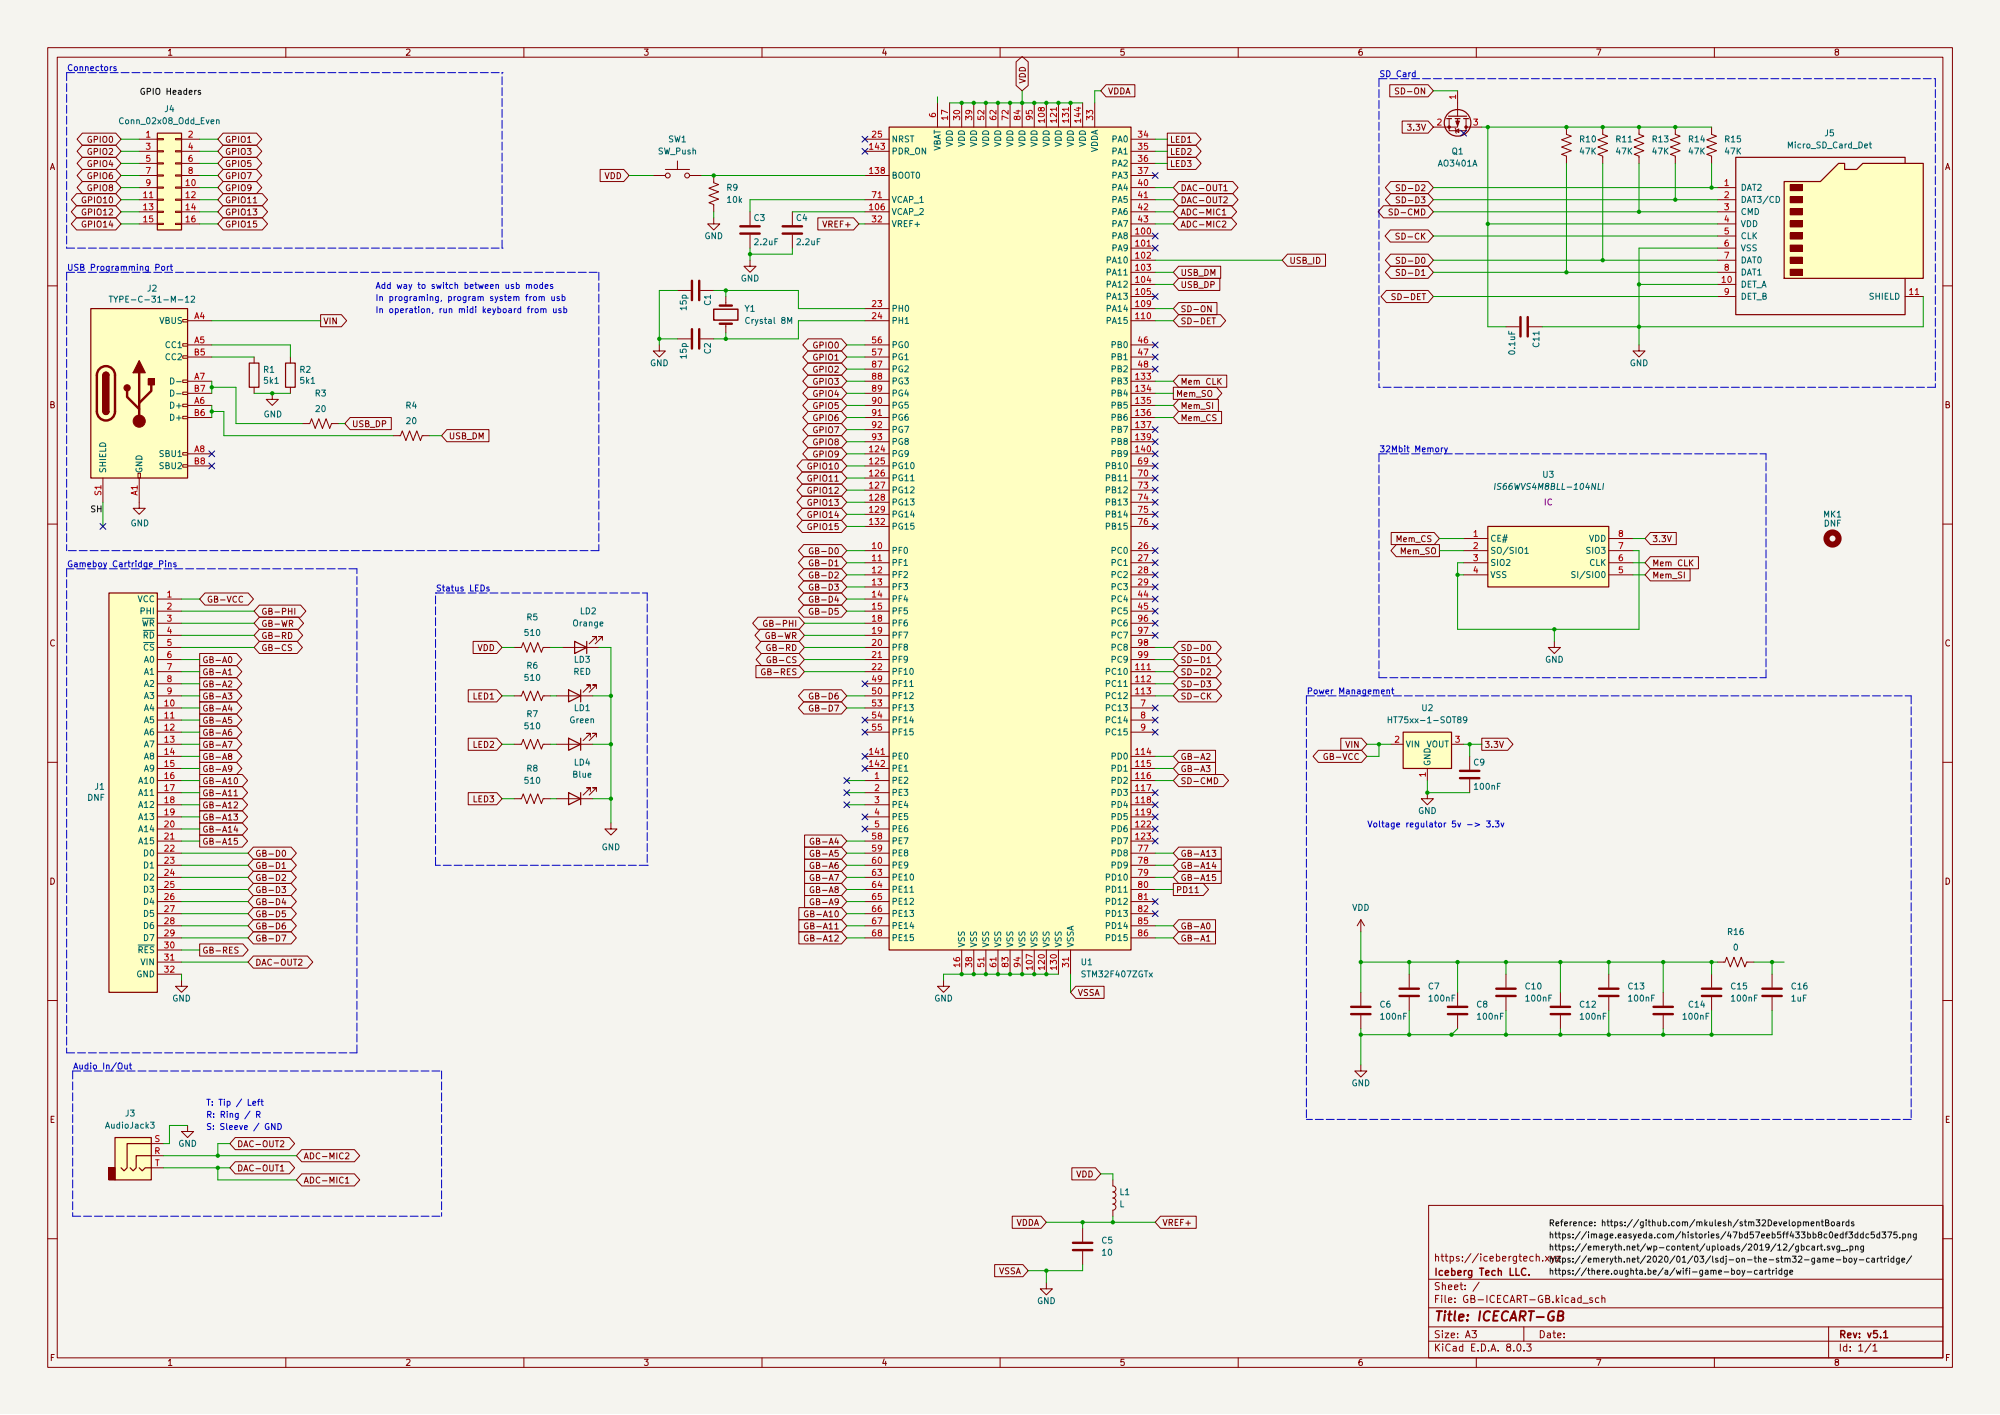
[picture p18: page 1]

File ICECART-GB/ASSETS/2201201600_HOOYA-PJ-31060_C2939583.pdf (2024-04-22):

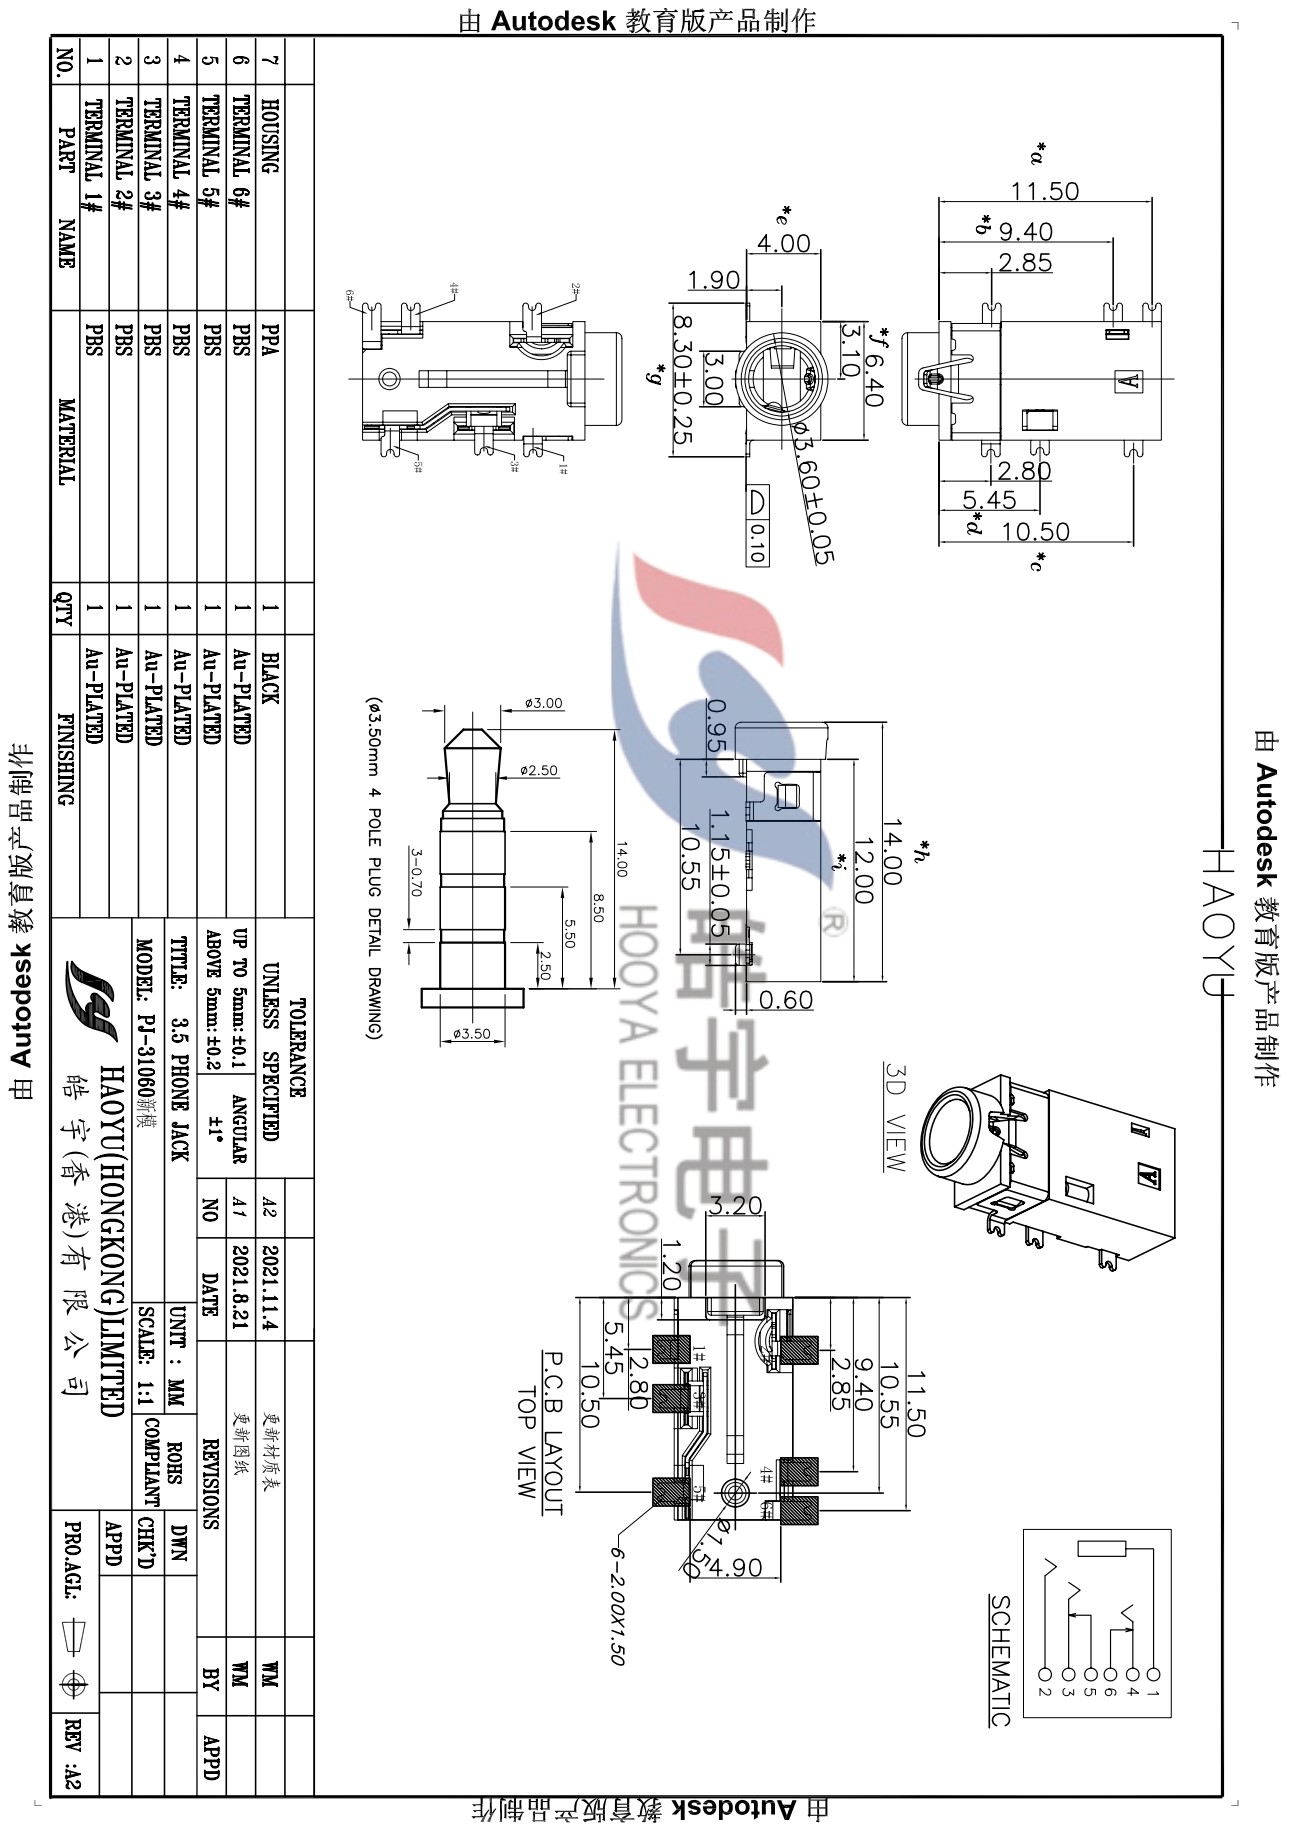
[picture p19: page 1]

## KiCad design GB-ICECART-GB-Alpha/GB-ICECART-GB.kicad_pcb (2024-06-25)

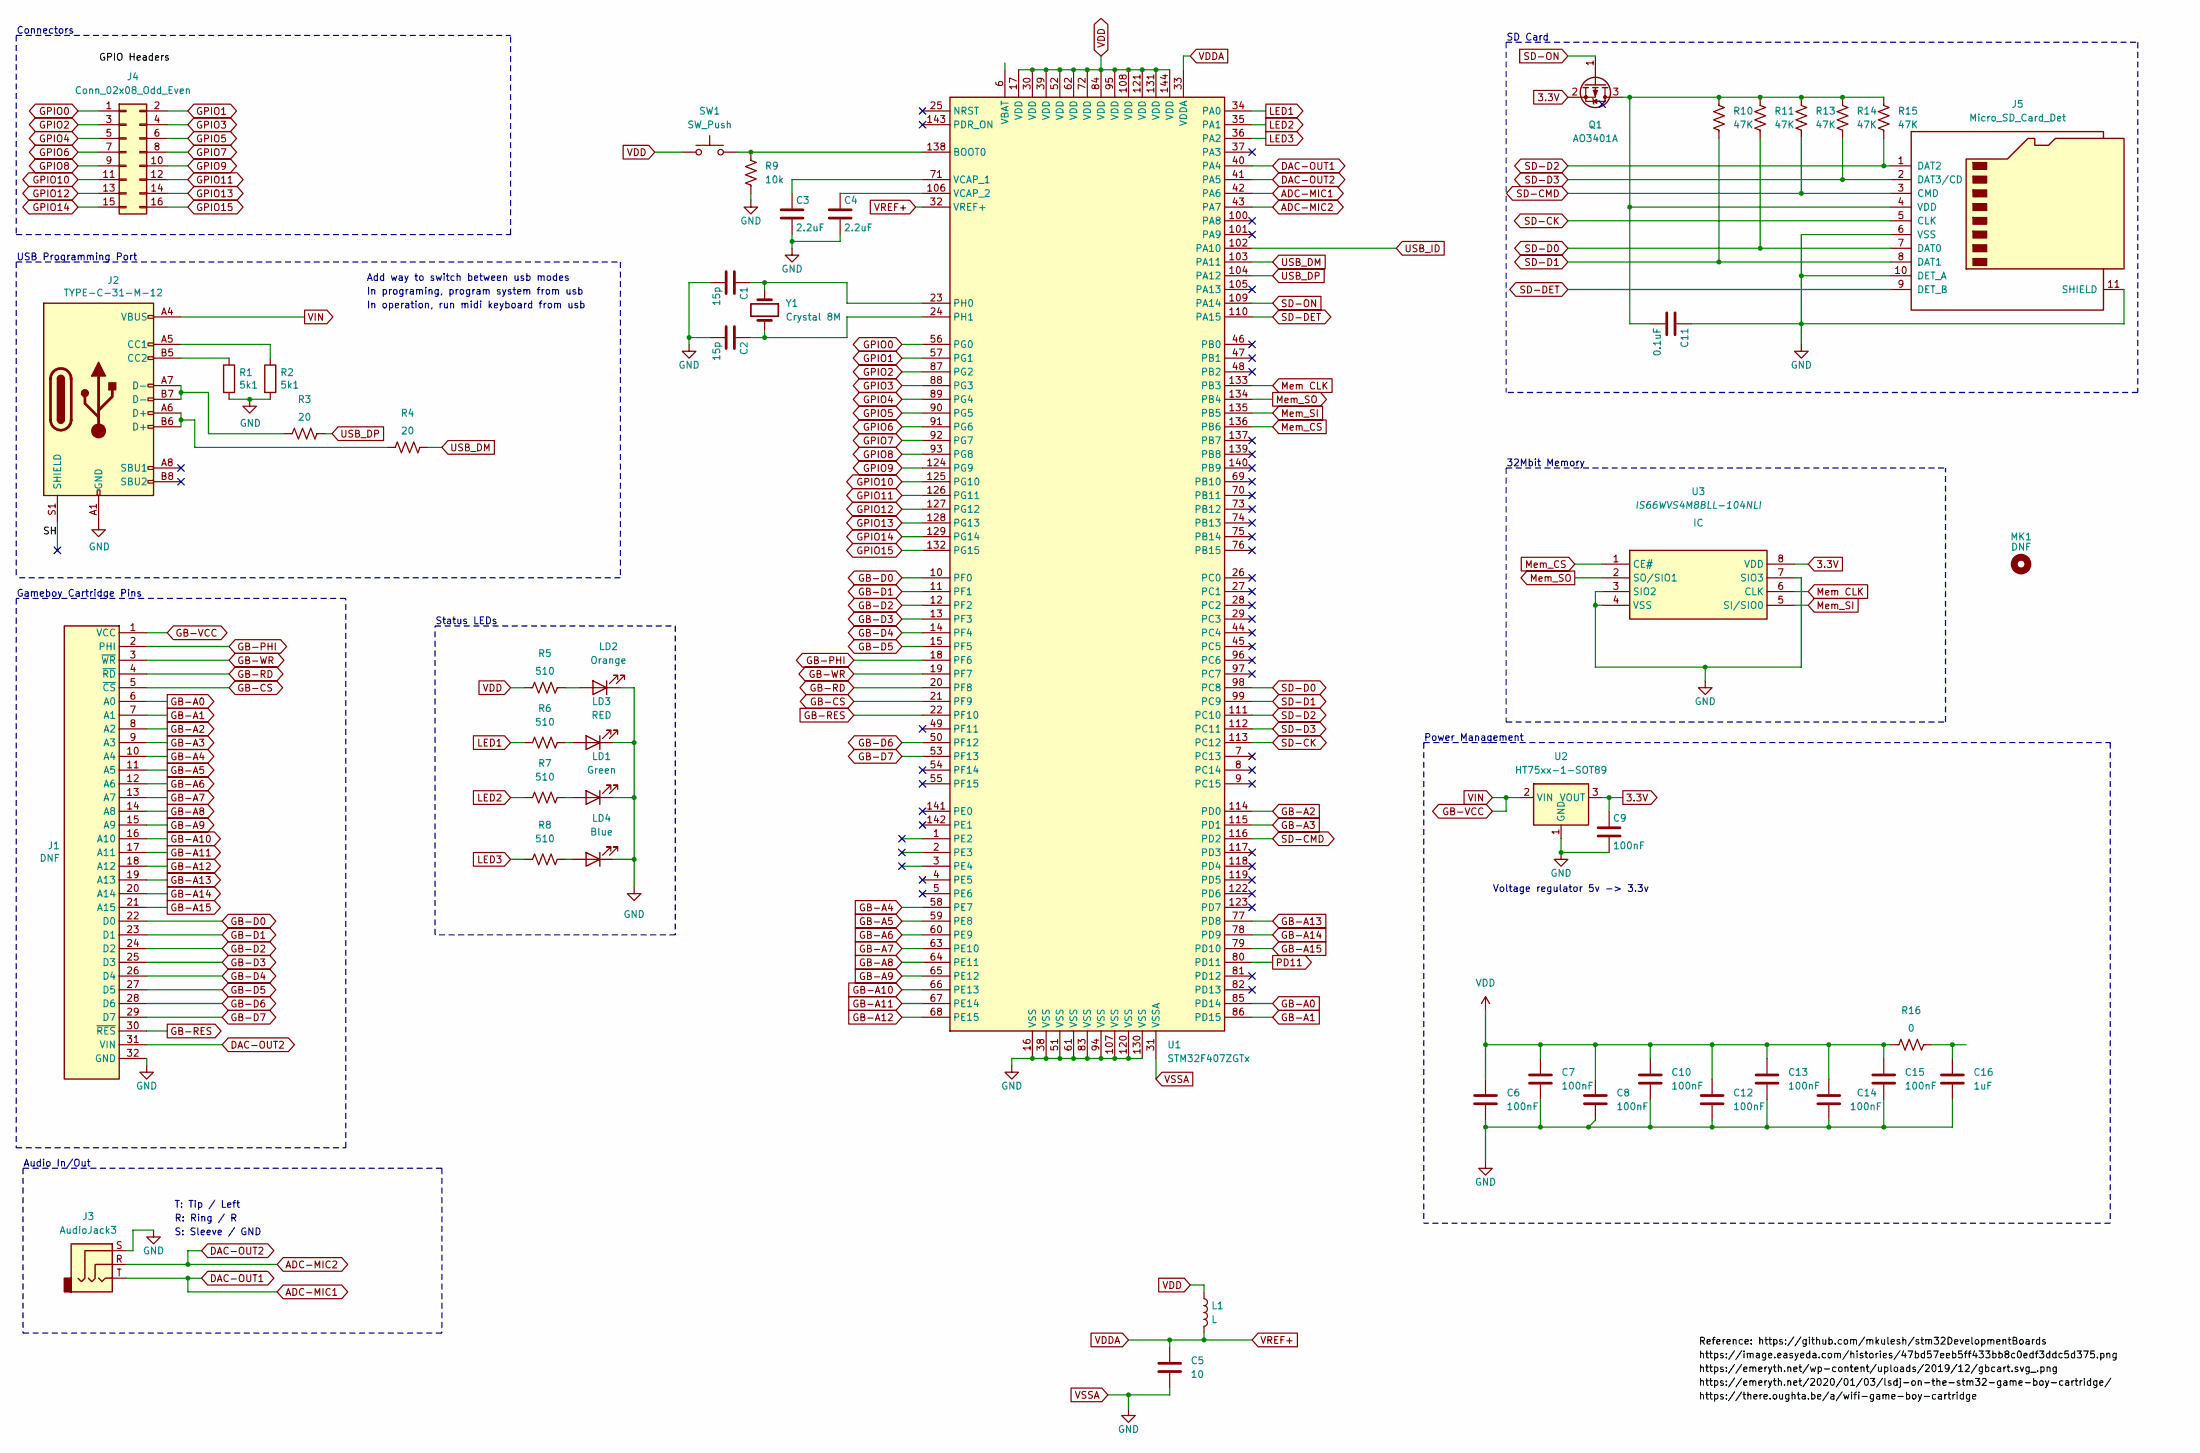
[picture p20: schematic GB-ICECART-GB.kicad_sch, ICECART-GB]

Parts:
C1, C2: 15p; C_0603_1608Metric; Rating 16V X5R; MPN 06035C104KAT4A
C3, C4: 2.2uF; C_0603_1608Metric; Rating 16V X5R; MPN 06035C104KAT4A
C5: 10; C_0603_1608Metric
C6, C7, C8, C10, C12, C13, C14, C15: 100nF; C_0603_1608Metric
C9: 100nF; C_0603_1608Metric; Rating 16V X5R; MPN 06035C104KAT4A
C11: 0.1uF; C_0603_1608Metric; Rating 16V X5R; MPN 06035C104KAT4A
C16: 1uF; C_0603_1608Metric
J1: DNF; GameBoy_Cartridge_1x32_P1.50mm_Edge
J2: TYPE-C-31-M-12; USB_C_Receptacle_HRO_TYPE-C-31-M-12
J3: AudioJack3; Jack_3.5mm_CUI_SJ1-3523N_Horizontal
J4: Conn_02x08_Odd_Even; IDC-Header_2x08_P2.54mm_Vertical_SMD
J5: Micro_SD_Card_Det; microSD_HC_Hirose_DM3AT-SF-PEJM5
L1: L; L_6.3x6.3_H3
LD1: Green; LED_0603_1608Metric
LD2: Orange; LED_0603_1608Metric
LD3: RED; LED_0603_1608Metric
LD4: Blue; LED_0603_1608Metric
MK1: DNF; MountingHole_7.2mm
Q1: AO3401A; SOT-23
R1, R2: 5k1; R_0603_1608Metric
R3, R4: 20; R_0603_1608Metric
R5, R6, R7, R8: 510; R_0603_1608Metric
R9: 10k; R_0603_1608Metric
R10, R11, R13, R14, R15: 47K; R_0603_1608Metric
R16: 0; R_0603_1608Metric
SW1: SW_Push; SW_SPST_B3U-1000P
U1: STM32F407ZGTx; LQFP-144_20x20mm_P0.5mm
U2: HT75xx-1-SOT89; SOT-89-3
U3: IS66WVS4M8BLL-104NLI; SOIC127P600X175-8N; Mouser Part Number 870-ISS4M8BLL-104NLI
Y1: Crystal 8M; Crystal_SMD_TXC_7M-4Pin_3.2x2.5mm

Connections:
3.3V: C9.1, Q1.2 (S), U2.3 (VOUT), U3.8 (VDD)
/SH: J2.S1 (SHIELD)
/SH_0: J2.S1 (SHIELD)
/SH_1: J2.S1 (SHIELD)
/SH_2: J2.S1 (SHIELD)
ADC-MIC1: J3.T, U1.40 (PA4), U1.42 (PA6)
ADC-MIC2: J1.31 (VIN), J3.R, U1.41 (PA5), U1.43 (PA7)
GB-A0: J1.6 (A0), U1.85 (PD14)
GB-A1: J1.7 (A1), U1.86 (PD15)
GB-A2: J1.8 (A2), U1.114 (PD0)
GB-A3: J1.9 (A3), U1.115 (PD1)
GB-A4: J1.10 (A4), U1.58 (PE7)
GB-A5: J1.11 (A5), U1.59 (PE8)
GB-A6: J1.12 (A6), U1.60 (PE9)
GB-A7: J1.13 (A7), U1.63 (PE10)
GB-A8: J1.14 (A8), U1.64 (PE11)
GB-A9: J1.15 (A9), U1.65 (PE12)
GB-A10: J1.16 (A10), U1.66 (PE13)
GB-A11: J1.17 (A11), U1.67 (PE14)
GB-A12: J1.18 (A12), U1.68 (PE15)
GB-A13: J1.19 (A13), U1.77 (PD8)
GB-A14: J1.20 (A14), U1.78 (PD9)
GB-A15: J1.21 (A15), U1.79 (PD10)
GB-CS: J1.5 (~CS), U1.21 (PF9)
GB-D0: J1.22 (D0), U1.10 (PF0)
GB-D1: J1.23 (D1), U1.11 (PF1)
GB-D2: J1.24 (D2), U1.12 (PF2)
GB-D3: J1.25 (D3), U1.13 (PF3)
GB-D4: J1.26 (D4), U1.14 (PF4)
GB-D5: J1.27 (D5), U1.15 (PF5)
GB-D6: J1.28 (D6), U1.50 (PF12)
GB-D7: J1.29 (D7), U1.53 (PF13)
GB-PHI: J1.2 (PHI), U1.18 (PF6)
GB-RD: J1.4 (~RD), U1.20 (PF8)
GB-RES: J1.30 (~RES), U1.22 (PF10)
GB-VCC: J1.1 (VCC), J2.A4 (VBUS), J2.A9 (VBUS), J2.B4 (VBUS), J2.B9 (VBUS), U2.2 (VIN)
GB-WR: J1.3 (~WR), U1.19 (PF7)
GPIO0: J4.1, U1.56 (PG0)
GPIO1: J4.2, U1.57 (PG1)
GPIO2: J4.3, U1.87 (PG2)
GPIO3: J4.4, U1.88 (PG3)
GPIO4: J4.5, U1.89 (PG4)
GPIO5: J4.6, U1.90 (PG5)
GPIO6: J4.7, U1.91 (PG6)
GPIO7: J4.8, U1.92 (PG7)
GPIO8: J4.9, U1.93 (PG8)
GPIO9: J4.10, U1.124 (PG9)
GPIO10: J4.11, U1.125 (PG10)
GPIO11: J4.12, U1.126 (PG11)
GPIO12: J4.13, U1.127 (PG12)
GPIO13: J4.14, U1.128 (PG13)
GPIO14: J4.15, U1.129 (PG14)
GPIO15: J4.16, U1.132 (PG15)
LED1: R6.1, U1.34 (PA0)
LED2: R7.1, U1.35 (PA1)
LED3: R8.1, U1.36 (PA2)
Mem CLK: U1.133 (PB3), U3.6 (CLK)
Mem_CS: U1.136 (PB6), U3.1 (CE#)
Mem_SI: U1.135 (PB5), U3.5 (SI/SIO0)
Mem_SO: U1.134 (PB4), U3.2 (SO/SIO1)
unnamed: C16.1, R16.2
unnamed: J2.A5 (CC1), R2.1
unnamed: J2.B5 (CC2), R1.1
unnamed: J2.A6 (D+), J2.B6 (D+), R4.1
unnamed: J2.A7 (D-), J2.B7 (D-), R3.1
unnamed: C11.2, J5.4 (VDD), Q1.3 (D), R10.1, R11.1, R13.1, R14.1, R15.1
unnamed: LD1.2 (A), R7.2
unnamed: LD2.2 (A), R5.2
unnamed: LD3.2 (A), R6.2
unnamed: LD4.2 (A), R8.2
unnamed: R9.1, SW1.2, U1.138 (BOOT0)
unnamed: C1.1, U1.23 (PH0), Y1.1
unnamed: C2.1, U1.24 (PH1), Y1.2
unnamed: C3.1, U1.71 (VCAP_1)
unnamed: C4.1, U1.106 (VCAP_2)
PD11: U1.80 (PD11)
SD-CK: J5.5 (CLK), U1.113 (PC12)
SD-CMD: J5.3 (CMD), R13.2, U1.116 (PD2)
SD-D0: J5.7 (DAT0), R11.2, U1.98 (PC8)
SD-D1: J5.8 (DAT1), R10.2, U1.99 (PC9)
SD-D2: J5.1 (DAT2), R15.2, U1.111 (PC10)
SD-D3: J5.2 (DAT3/CD), R14.2, U1.112 (PC11)
SD-DET: J5.9 (DET_B), U1.110 (PA15)
SD-ON: Q1.1 (G), U1.109 (PA14)
USB_DM: R4.2, U1.103 (PA11)
USB_DP: R3.2, U1.104 (PA12)
USB_ID: U1.102 (PA10)
VDD: C6.1, C7.1, C8.1, C10.1, C12.1, C13.1, C14.1, C15.1, L1.1, R5.1, R16.1, SW1.1, U1.17 (VDD), U1.30 (VDD), U1.39 (VDD), U1.52 (VDD), U1.62 (VDD), U1.72 (VDD), U1.84 (VDD), U1.95 (VDD), U1.108 (VDD), U1.121 (VDD), U1.131 (VDD), U1.144 (VDD)
VDDA: C5.1, L1.2, U1.32 (VREF+), U1.33 (VDDA)
VSSA: C1.2, C2.2, C3.2, C4.2, C5.2, C6.2, C7.2, C8.2, C9.2, C10.2, C11.1, C12.2, C13.2, C14.2, C15.2, C16.2, J1.32 (GND), J2.A1 (GND), J2.A12 (GND), J2.B1 (GND), J2.B12 (GND), J3.S, J5.6 (VSS), J5.10 (DET_A), J5.11 (SHIELD), LD1.1 (K), LD2.1 (K), LD3.1 (K), LD4.1 (K), R1.2, R2.2, R9.2, U1.16 (VSS), U1.31 (VSSA), U1.38 (VSS), U1.51 (VSS), U1.61 (VSS), U1.83 (VSS), U1.94 (VSS), U1.107 (VSS), U1.120 (VSS), U1.130 (VSS), U2.1 (GND), U3.3 (SIO2), U3.4 (VSS), U3.7 (SIO3)

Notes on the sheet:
USB Programming Port
SD Card
Audio In/Out
R: Ring / R
Connectors
S: Sleeve / GND
Add way to switch between usb modes
32Mbit Memory
T: Tip / Left
Status LEDs
In operation, run midi keyboard from usb
In programing, program system from usb
Power Management
Gameboy Cartridge Pins
Voltage regulator 5v -> 3.3v

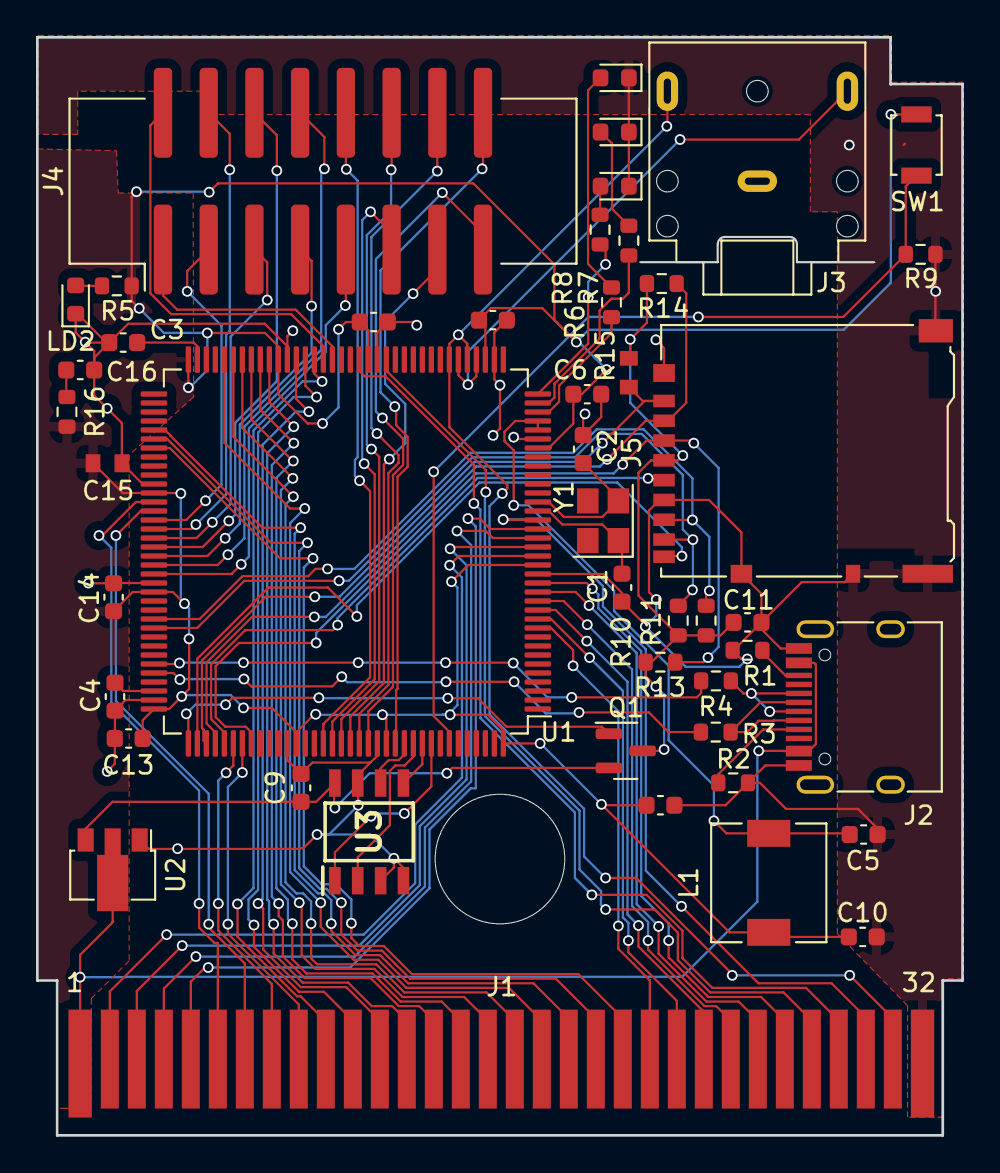
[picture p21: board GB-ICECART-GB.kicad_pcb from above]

Board: 2 copper layers, 51.4 x 61.0 mm, 48 parts (0 on the bottom side), 84 nets.

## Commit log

2023-11-28 Initial Prototyping and planning
    [EDI2CAP.CFG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]
2023-12-01 Add model of design
    [GB-ICECART-GB.kicad_pcb, GB-ICECART-GB.kicad_sch]
2023-12-06 Update schematic and hook more up
    [GB-ICECART-GB.kicad_sch]
2023-12-08 Add schematic and pcb design images
    [GB-ICECART-GB.kicad_pcb, GB-ICECART-GB.kicad_sch]
2024-04-22 Add new version
    [AUDIO_CODEC_MIC_ES8388.kicad_sch, CARTRIDGE.STEP, EDI2CAP.CFG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]
2024-06-25 Preliminary routing and BOM
    [GB-ICECART-GB-bom-test.csv, GB-ICECART-GB.kicad_pcb, GB-ICECART-GB.kicad_sch]
2024-06-25 Add JLC PCB export
    [bom.csv, designators.csv, positions.csv]
2025-05-19 setup pico gb
    [icecart-gb.kicad_sch]
